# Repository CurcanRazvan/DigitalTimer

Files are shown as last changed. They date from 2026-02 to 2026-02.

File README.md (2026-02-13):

# Digital Timer - University Practice Project

This is the project I built for my 2nd-year university practice module. It is a digital timer designed in KiCad, capable of counting seconds (0-59) and displaying them on two 7-segment displays.

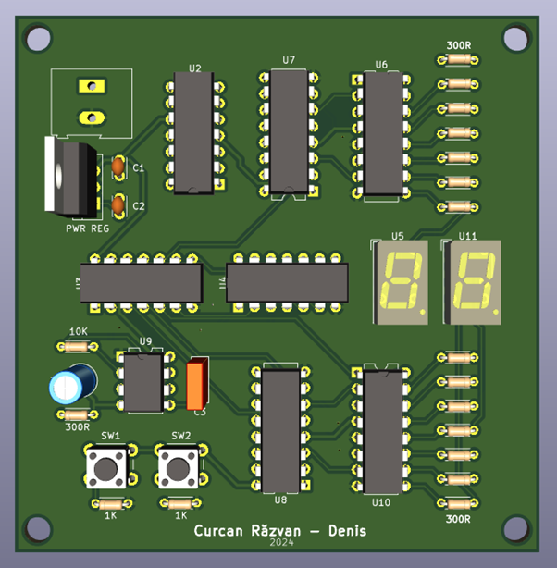
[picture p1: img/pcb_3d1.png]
3D Render


### Technical Overview

The circuit is designed with a modular approach:
1.  **Clock Signal:** Generated by an **NE555** timer configured as an astable oscillator.
2.  **Counting:** Handled by two **74LS193** 4-bit synchronous binary counters (U7 and U8).
3.  **Decoding & Display:** The binary signal is converted for the 7-segment displays using **CD4511** decoders.

**Logic Control:**
I used additional logic gates (**74LS73, 74LS08, CD4071**) to handle the counting limit (resetting at 60) and the Up/Down direction control.

### Schematic
Here is the final schematic, which includes the corrections needed for everything to work properly:

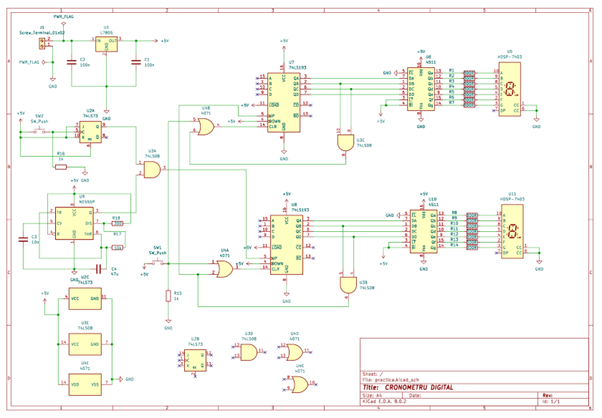
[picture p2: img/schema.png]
KiCad Schematic


### v1.0 & Debugging

After getting the PCB manufactured and soldering the components, I spotted a mistake in the initial schematic: Pin 11 (Load) on the counters wasn't connected to 5V, and the C4 capacitor (47uF) wasn't linked to resistor R17.

**The Fix:**
I fixed this directly on the board by adding two jumper wires on the bottom layer.
* The red wires visible in the photo below connect the pins to 5V and route the capacitor correctly.
* With these changes, the circuit works perfectly.

| Top Layer (Components) | Bottom Layer (The Red Wire Fix) |
|:---:|:---:|
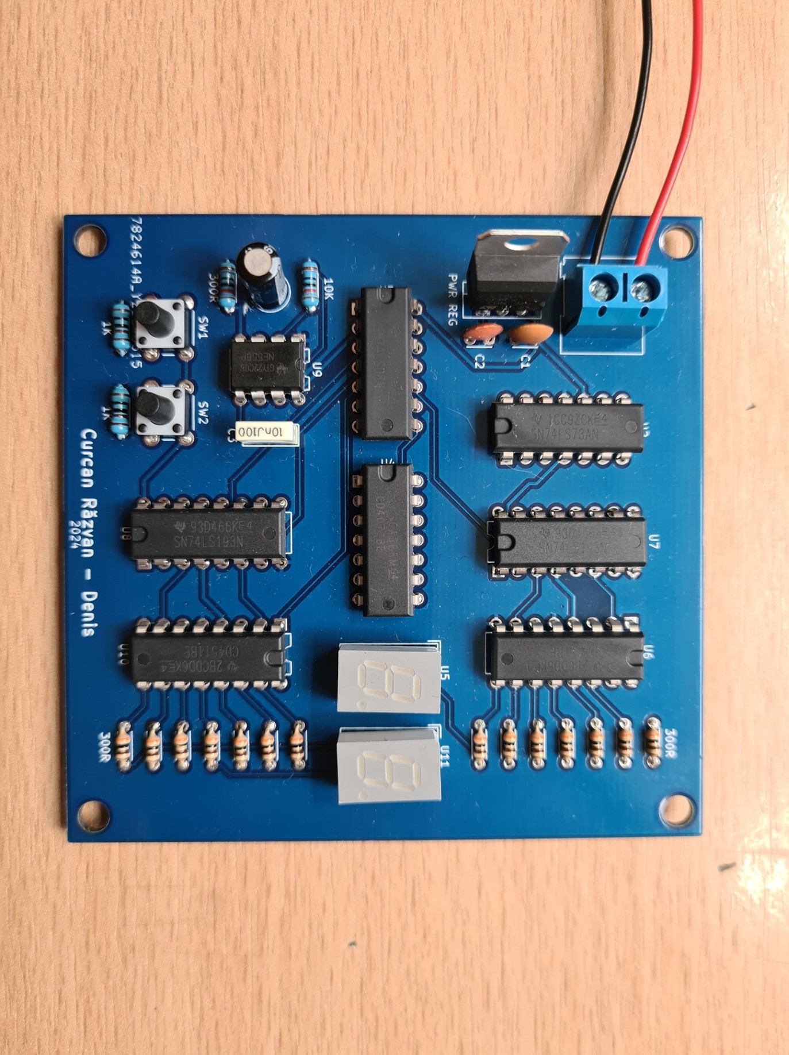
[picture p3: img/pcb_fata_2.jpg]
PCB Front
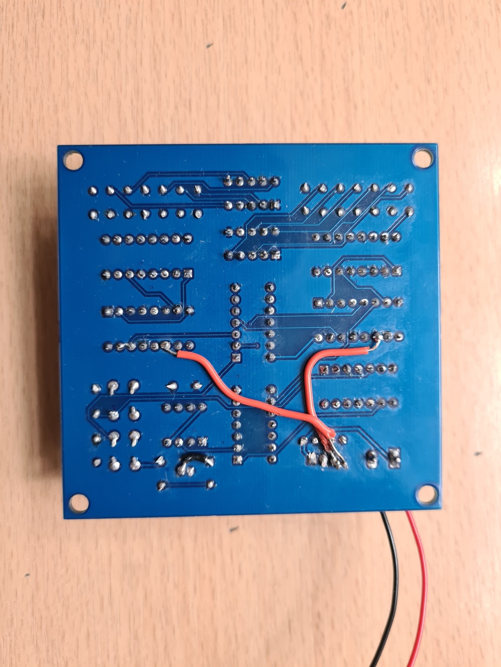
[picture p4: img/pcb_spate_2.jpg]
PCB Back with wires
|  |  |

### Bill of Materials (BOM)

The total cost for the project (components + PCB + shipping) was approximately 140 Lei (~$30).

| Ref | Component | Description |
|:---|:---|:---|
| U9 | **NE555P** | Precision Timer |
| U7, U8 | **SN74LS193N** | Sync Binary Counter UP/DOWN |
| U6, U10 | **CD4511BE** | BCD to 7-Segment Decoder |
| U5, U11 | **HDSP-5601** | 7-Segment Display |
| U1 | **L7805** | 5V Voltage Regulator |
| U2 | **SN74LS73AN** | Dual JK Flip-Flop |
| U3 | **SN74LS08N** | Quad 2-Input AND Gate |
| U4 | **CD4071BE** | Quad 2-Input OR Gate |
| - | **9V Battery** | Power Source |

### Repository Structure
* `/kicad` - Source files (.sch, .kicad_pcb)
* `/img` - Images and renders

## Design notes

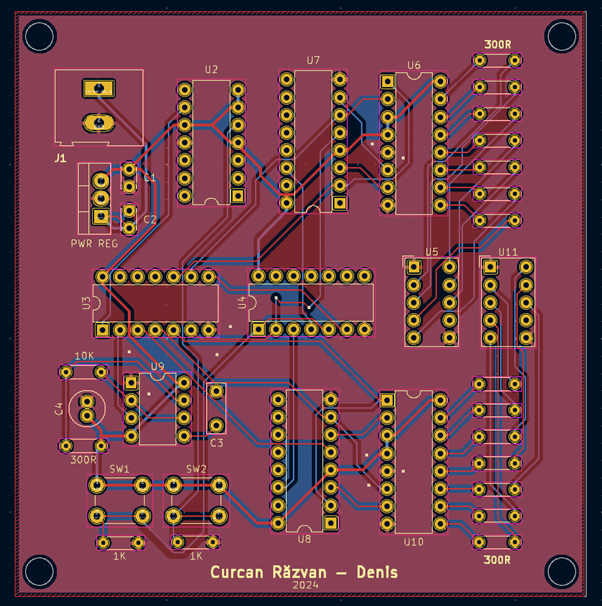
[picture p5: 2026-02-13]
img/pcb_3d.png

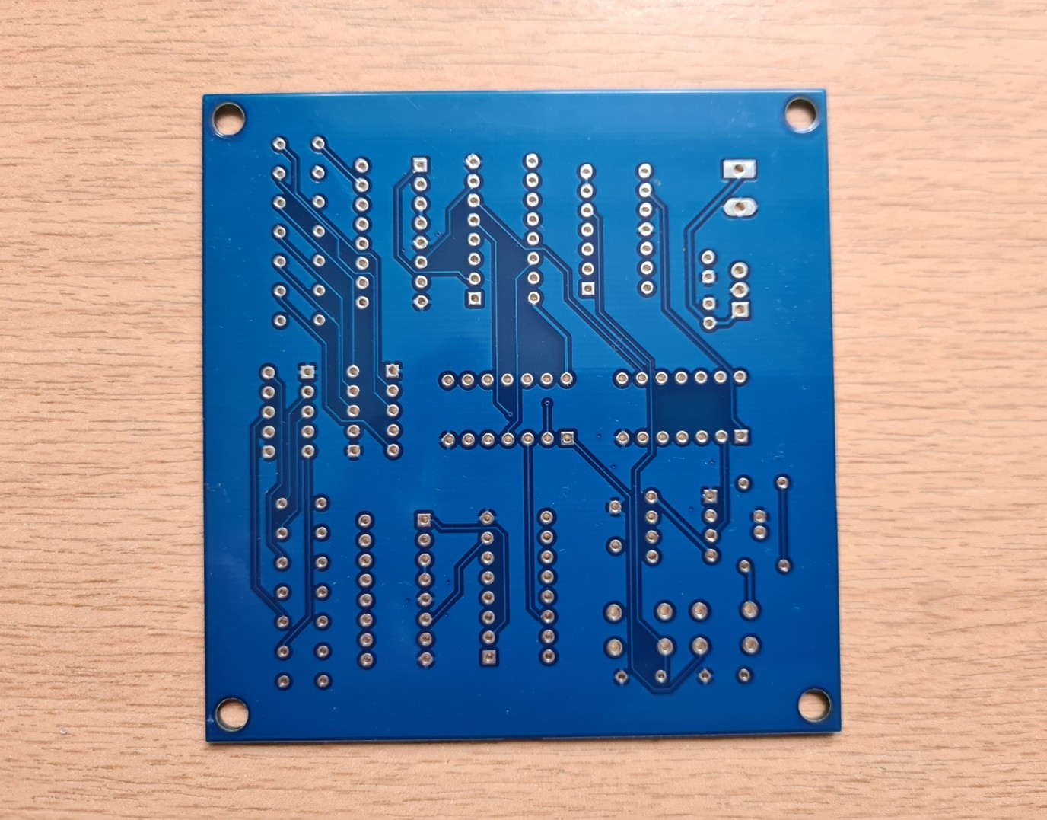
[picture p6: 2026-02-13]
img/pcb_spate_1.jpg

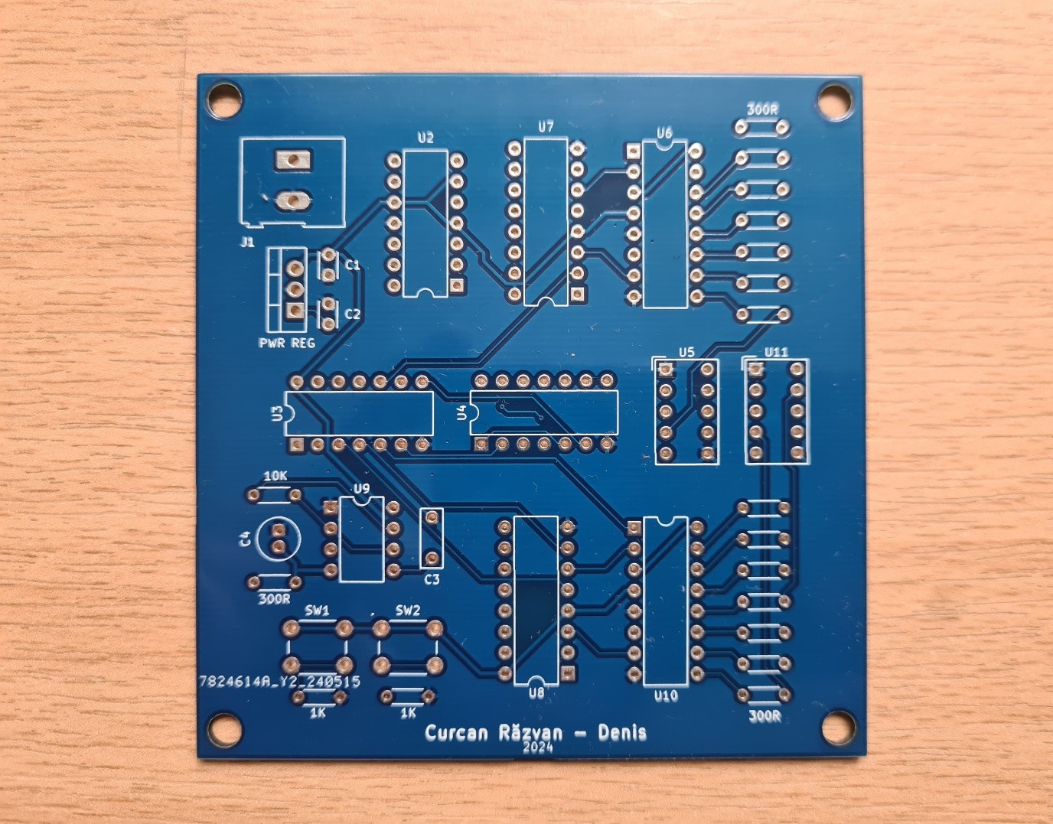
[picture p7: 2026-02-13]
img/pcb_fata_1.jpg

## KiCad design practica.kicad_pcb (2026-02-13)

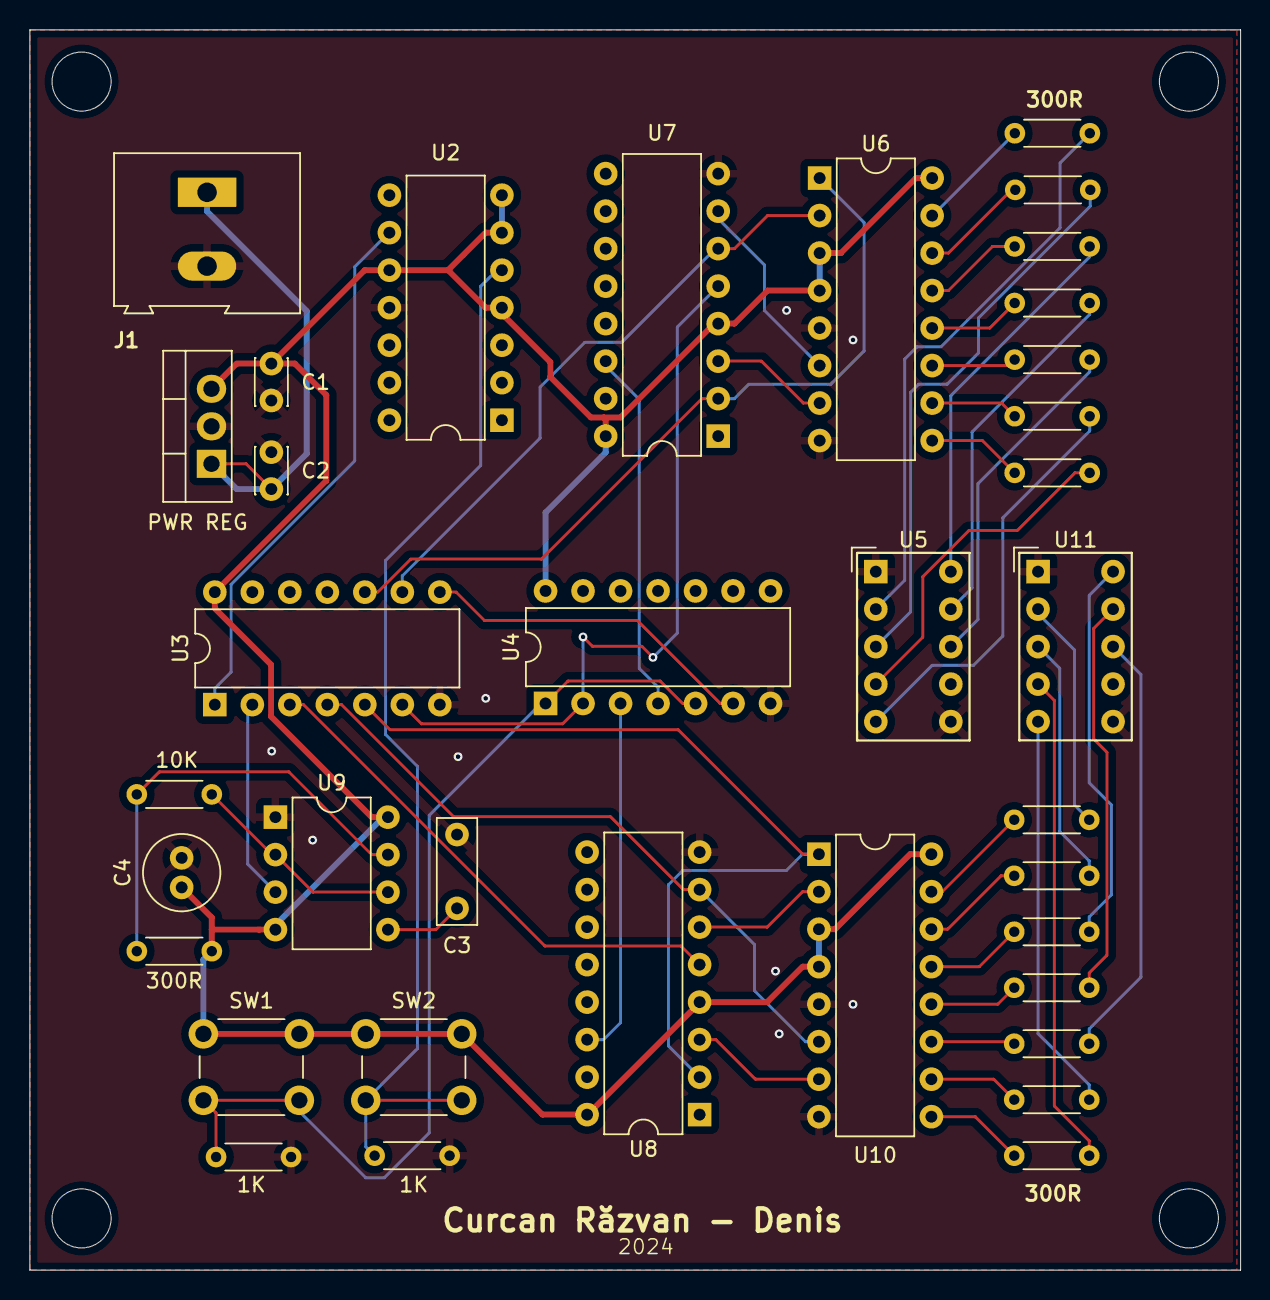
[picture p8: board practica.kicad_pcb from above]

Board: 2 copper layers, 82.0 x 84.0 mm, 36 parts (0 on the bottom side), 51 nets.

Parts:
1K, 1K#2: 1k; R_Axial_DIN0204_L3.6mm_D1.6mm_P5.08mm_Horizontal
10K: 10k; R_Axial_DIN0204_L3.6mm_D1.6mm_P5.08mm_Horizontal
300R: 300; R_Axial_DIN0204_L3.6mm_D1.6mm_P5.08mm_Horizontal
C1, C2: 100n; C_Disc_D3.0mm_W2.0mm_P2.50mm
C3: 10n; C_Rect_L7.0mm_W2.5mm_P5.00mm
C4: 47u; C_Radial_D5.0mm_H11.0mm_P2.00mm
J1: Screw_Terminal_01x02; TerminalBlock_Altech_AK300-2_P5.00mm
PWR REG: L7805; TO-220-3_Vertical
R1, R2, R3, R4, R5, R6, R7, R8, R9, R10, R11, R12, R13, R14: 300R; R_Axial_DIN0204_L3.6mm_D1.6mm_P5.08mm_Horizontal
SW1: SW_Push; SW_PUSH_6mm
SW2: SW_Start_Stop; SW_PUSH_6mm
U2: 74LS73; DIP-14_W7.62mm
U3: 74LS08; DIP-14_W7.62mm
U4: 4071; DIP-14_W7.62mm
U5, U11: HDSP-7403; HDSP-7401
U6, U10: 4511; DIP-16_W7.62mm
U7, U8: 74LS193; DIP-16_W7.62mm
U9: NE555D; DIP-8_W7.62mm

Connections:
+5V: 300R.2, C1.1, C4.2, PWR REG.3 (OUT), SW1.1, SW2.1, U2.4 (VCC), U2.6 (~R), U2.7 (J), U2.10 (K), U3.14 (VCC), U4.14 (VDD), U6.3 (~LT), U6.4 (~BI), U6.16 (Vdd), U7.4 (DOWN), U7.16 (VCC), U8.4 (DOWN), U8.16 (VCC), U9.4 (R), U9.8 (VCC), U10.3 (~LT), U10.4 (~BI), U10.16 (Vdd)
GND: 1K.2, 1K#2.2, C1.2, C2.2, C3.1, C4.1, J1.2, PWR REG.2 (GND), U2.11 (GND), U3.7 (GND), U4.7 (VSS), U5.1 (CC), U5.6 (CC), U6.5 (~EL), U6.8 (Vss), U7.8 (GND), U8.8 (GND), U9.1 (GND), U10.5 (~EL), U10.8 (Vss), U11.1 (CC), U11.6 (CC)
unnamed: C2.1, J1.1, PWR REG.1 (IN)
unnamed: 1K.1, SW1.2, U4.1, U4.5
unnamed: 1K#2.1, SW2.2, U2.5 (C)
unnamed: U2.9 (Q), U3.1
unnamed: U3.8, U4.6
unnamed: R1.2, U5.10 (A)
unnamed: R2.2, U5.9 (B)
unnamed: R3.2, U5.8 (C)
unnamed: R4.2, U5.5 (D)
unnamed: R5.2, U5.4 (E)
unnamed: R6.2, U5.2 (F)
unnamed: R7.2, U5.3 (G)
unnamed: U6.7 (DA), U7.3 (QA)
unnamed: U3.10, U6.1 (DB), U7.2 (QB)
unnamed: U3.9, U6.2 (DC), U7.6 (QC)
unnamed: U6.6 (DD), U7.7 (QD)
unnamed: R1.1, U6.13 (Qa)
unnamed: R2.1, U6.12 (Qb)
unnamed: R3.1, U6.11 (Qc)
unnamed: R4.1, U6.10 (Qd)
unnamed: R5.1, U6.9 (Qe)
unnamed: R6.1, U6.15 (Qf)
unnamed: R7.1, U6.14 (Qg)
unnamed: U4.4, U7.14 (CLR)
unnamed: U3.6, U4.2, U7.5 (UP)
unnamed: U4.3, U8.14 (CLR)
unnamed: U3.3, U8.5 (UP)
unnamed: C3.2, U9.5 (CV)
unnamed: 10K.2, 300R.1, U9.7 (DIS)
unnamed: U3.2, U9.3 (Q)
unnamed: 10K.1, U9.2 (TR), U9.6 (THR)
unnamed: U8.3 (QA), U10.7 (DA)
unnamed: U3.5, U8.2 (QB), U10.1 (DB)
unnamed: U8.6 (QC), U10.2 (DC)
unnamed: U3.4, U8.7 (QD), U10.6 (DD)
unnamed: R8.1, U10.13 (Qa)
unnamed: R9.1, U10.12 (Qb)
unnamed: R10.1, U10.11 (Qc)
unnamed: R11.1, U10.10 (Qd)
unnamed: R12.1, U10.9 (Qe)
unnamed: R13.1, U10.15 (Qf)
unnamed: R14.1, U10.14 (Qg)
unnamed: R8.2, U11.10 (A)
unnamed: R9.2, U11.9 (B)
unnamed: R10.2, U11.8 (C)
unnamed: R11.2, U11.5 (D)
unnamed: R12.2, U11.4 (E)
unnamed: R13.2, U11.2 (F)
unnamed: R14.2, U11.3 (G)

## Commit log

2026-02-13 Initial commit - 2nd year practice project
    [practica.kicad_pcb, practica.kicad_sch]
2026-02-13 Add README with project details and specifications
    Added detailed project description, technical specifications, electrical schematic, debugging iteration, materials list, and repository structure.
